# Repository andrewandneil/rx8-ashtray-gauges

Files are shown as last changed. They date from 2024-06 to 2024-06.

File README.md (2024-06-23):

# Mazda RX-8 Ashtray Gauges

As someone who likes knowing the vitals of my ever-so-fragile rotary engine, I wanted a way to monitor Oil Temperature, Oil Pressure, Coolant Temperature and Electrical System Voltage without needing big aftermarket gauges. I stumbled across Stephane Gilbert's work, where he built a small gauge system for coolant temperature, pressure and battery voltage, but it wasn't a perfect fit for me. I decided to take his basis, and modify it to my need. After several months of toiling around, I have finally produced this:

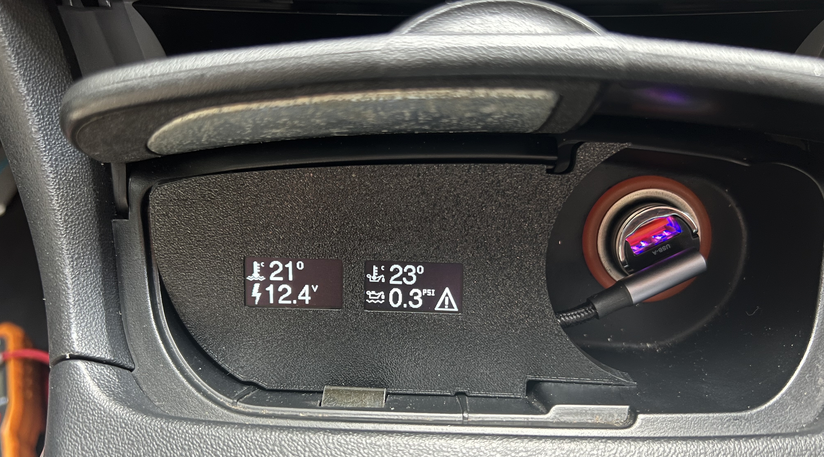
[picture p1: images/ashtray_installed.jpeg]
RX8 Ashtray Gauges Installed


This project doesn't use the OBDII port, instead relying on deidcated sensors. For both oil and coolant temperature AEM-30-2012 sensors were used and for oil pressure a 200 PSI pressure transducer was used. Electrical system voltage is calculated using the supplied power on board.

The design uses two PCBs, one PCB that houses the electronics, and another PCB inside the ashtray cavity to breakout the connectors for screens and sensors.

## Features
- Coolant Temperature Monitoring & Warning.
- Oil Temperature and Pressure Monitoring & Warning.
- System Voltage Monitoring & Warning.
- Screen auto-off when ashtray lid is closed.
- Optional LED warning lights when temperature, pressure or voltage is out of user specified limits.
- Optional buzzer sound when temperature, pressure or voltage is out of user specified limits. [NOT IMPLEMENTED ATM]

## Sensors
If you're building this yourself, this is where you can go your own route, you may prefer to use the oil filter sandwich plate, in which case disregard anything below. You also shouldnt need a 200 PSI sensor if you're using the sandwich plate, a 100 PSI sensor would be more appropriate (do your own research, this is what I've found searching around). You may also prefer to add your coolant temp sensor to the main radiator hose, in which case of course there are guides out there for that.

#### My Oil Temperature Sensor Location:
A modified banjo bolt with a 1/8NPT thread cut into the top is used. Add thread sealant to the NPT threads and not to the banjo bolt threads (that's what the crush washers are for). Mounted to the banjo bolt on the front passanger side oil cooler.

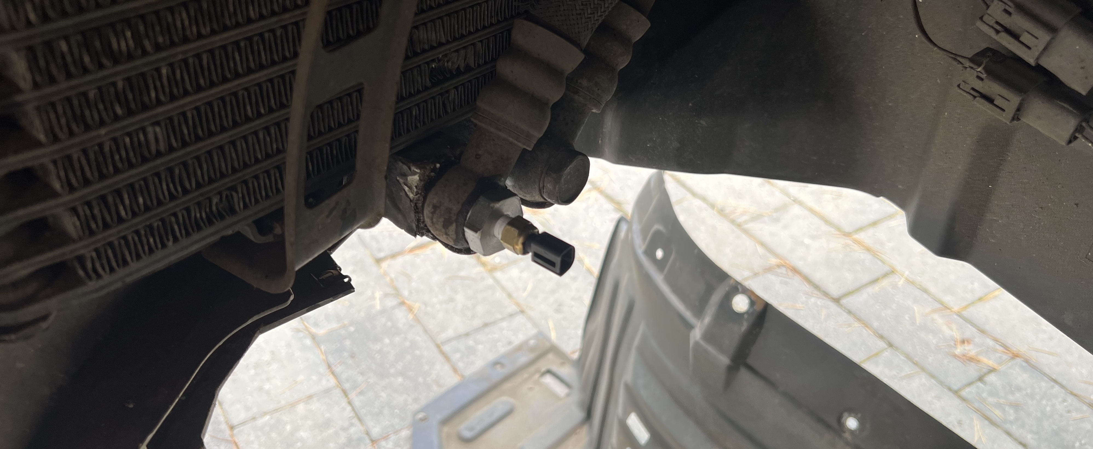
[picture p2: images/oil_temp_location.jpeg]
Oil Temp Sensor Location


#### My Oil Pressure Sensor Location:
A modified banjo bolt with a 1/8NPT thread cut into the top is used. Add thread sealant to the NPT threads and not to the banjo bolt threads (that's what the crush washers are for). Mounted to the banjo bolt on the feed line to the oil cooler.

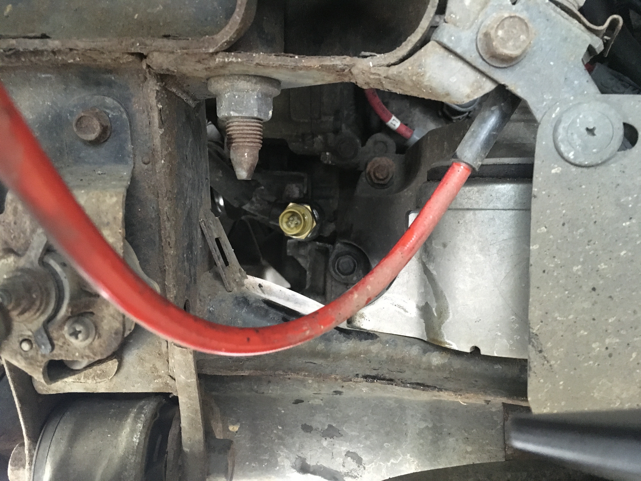
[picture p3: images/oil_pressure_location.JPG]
Oil Pressure Sensor Location


#### My Coolant Temperature Sensor Location:
A Racing Beat RX-8 Water Temp Sensor Hose Adapter is used with a 3/8 to 1/8 step down adapter to fit the 1/8NPT thread of the sensor. Add thread sealant to the threads on both the adapter and sensor. Fitted to the heater core hose located on the passanger side.

Coolant Temp Sensor Location

## 3D Printing
The cases for the electronics and the OLED screen holders are designed to be 3D printed by a standard FDM printer. 

### Electronics Housing
Recommended print settings:
- PETG or ABS/ASA (don't use PLA as it will warp when exposed to the sun or heat)
- 0.2mm Layer Height

You'll also need:
- x6 M3 Heat set inserts (OD: 4mm, Length: 4.2mm)
- x6 M3x10 Bolts
- x2 M3 Washers (for clamping the CPT power item to the board)

### OLED Screen Holder
Recommended print settings:
- PETG or ABS/ASA (don't use PLA as it will warp when exposed to the sun or heat)
- 0.1mm or 0.15mm Layer Height

You'll also need:
- x5 M3 Heat set inserts (OD: 4mm, Length: 4.2mm)
- x2 M3x10 Bolts
- x3 M3x4 Bolts

### OLED Screen Spacers
Print two, one for each oled screen.

Recommended print settings:
- PETG or ABS/ASA (don't use PLA as it will warp when exposed to the sun or heat)
- 0.2mm Layer Height

You'll also need:
- x8 M2.5x8 Dome Head Bolts (must be low profile)
- x8 M2.5 Nuts
- x8 M2.5 Washers

## Useful Links
A guide for adding the oil temperature and pressure sensors: https://www.rx8club.com/series-i-do-yourself-forum-73/diy-oil-temp-pressure-sender-install-modified-banjo-bolts-235867/

rx8-coolant-monitor by Stephane Gilbert (topolittle): https://github.com/topolittle/rx8-coolant-monitor

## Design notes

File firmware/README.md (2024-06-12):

# The Firmware

Open this folder using PlatformIO in Visual Studio Code (or VSCodium). Ensure you have the Adafruit GFX Library and Adafruit SSD1306 libraries installed (these should install automatically from the platformio.ini file on first opening).

IMPORTANT: To ensure proper temperature, pressure and battery voltage calculations, you need to measure the exact resistance of `R3`, `R4`, `R8`, `R9`, `R10` and `R11` and add these values to the marked sections in the `coolant_monitor.h` file.

For example, if you measured a resistance of 13.9K on the coolant high side resistor, change the line:
- `#define COOL_THERMISTOR_RESISTOR_REFERENCE_HIGH 15020.0` to `#define COOL_THERMISTOR_RESISTOR_REFERENCE_HIGH 13900.0`

You must add the `.0` at the end as the value must be reported as a float.

Build this by pressing the checkmark in the bottom left of the VS Code window, and then upload it to the Teensy using the onboard micro-USB port by pressing the right hand arrow in VS Code.

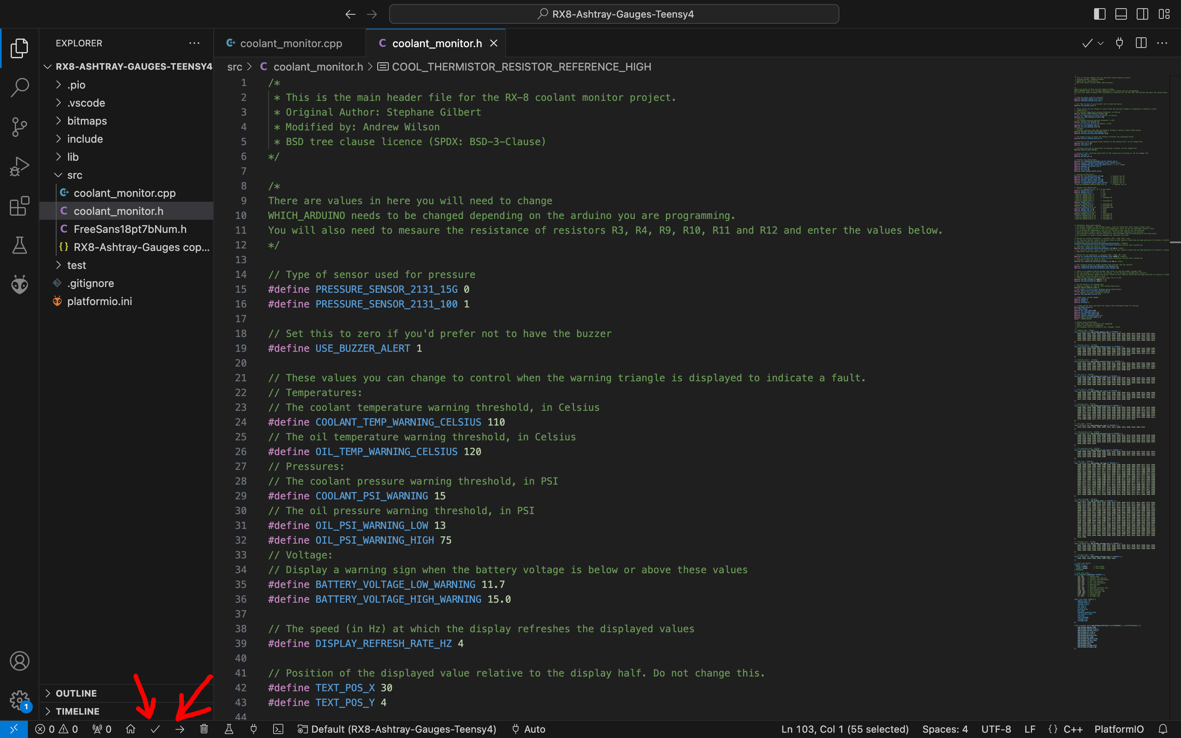
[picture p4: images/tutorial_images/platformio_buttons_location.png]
PlatformIO Button Locations


(Better tutorial to follow :) )

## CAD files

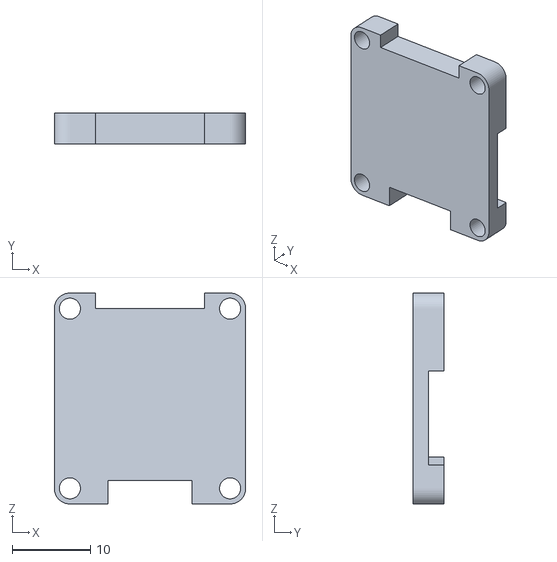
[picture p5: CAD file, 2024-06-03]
3d-models/ashtray_screens/ashtray_screen_spacer.stl
24.5 x 3.94 x 27.0

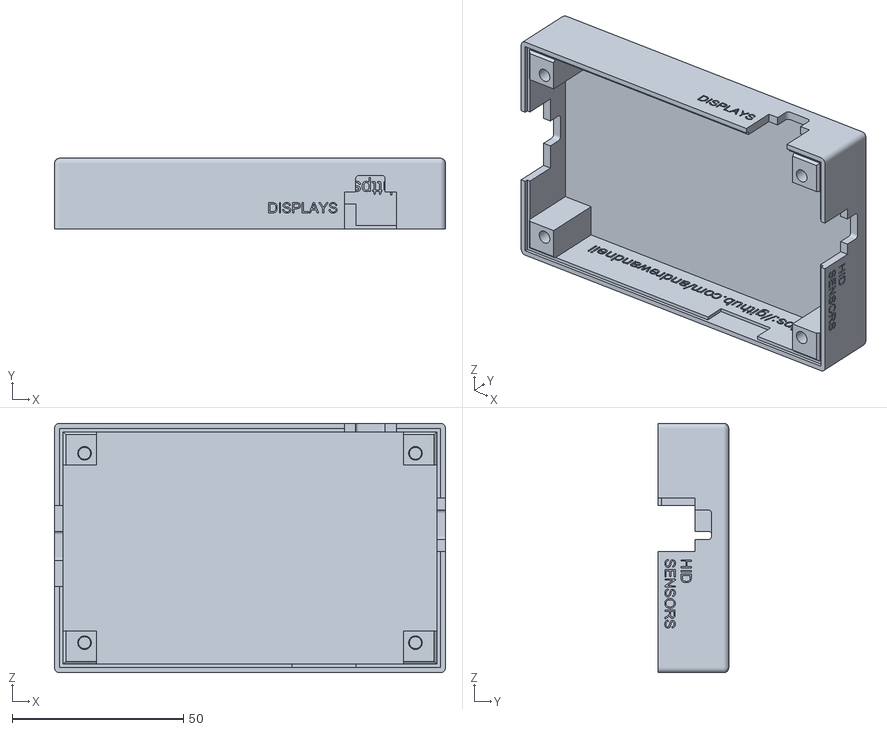
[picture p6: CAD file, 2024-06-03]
3d-models/pcb_housing/pcb_enclosure_top.stl
114.0 x 20.6 x 72.8

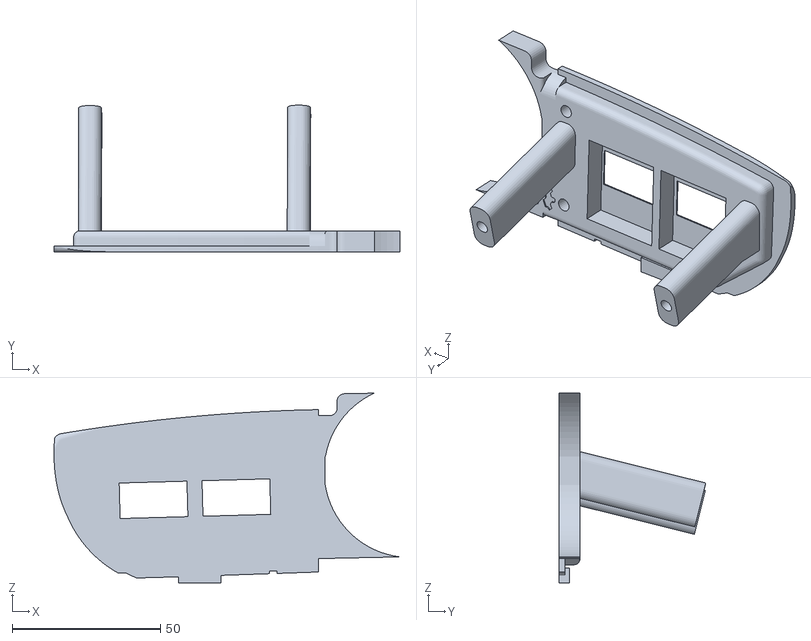
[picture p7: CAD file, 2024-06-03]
3d-models/ashtray_screens/ashtray_screen_no_led.stl
116.9 x 49.5 x 64.1

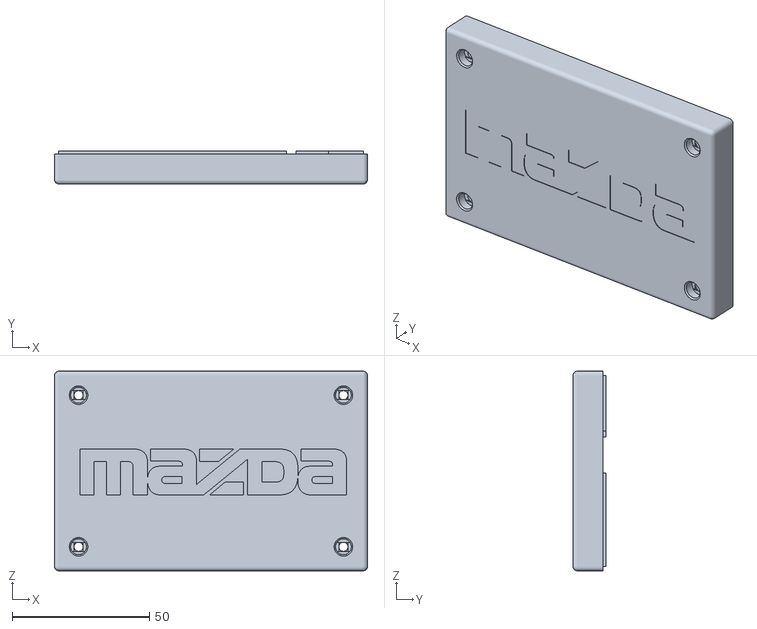
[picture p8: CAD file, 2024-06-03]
3d-models/pcb_housing/pcb_enclosure_bottom.stl
114.0 x 12.0 x 72.8

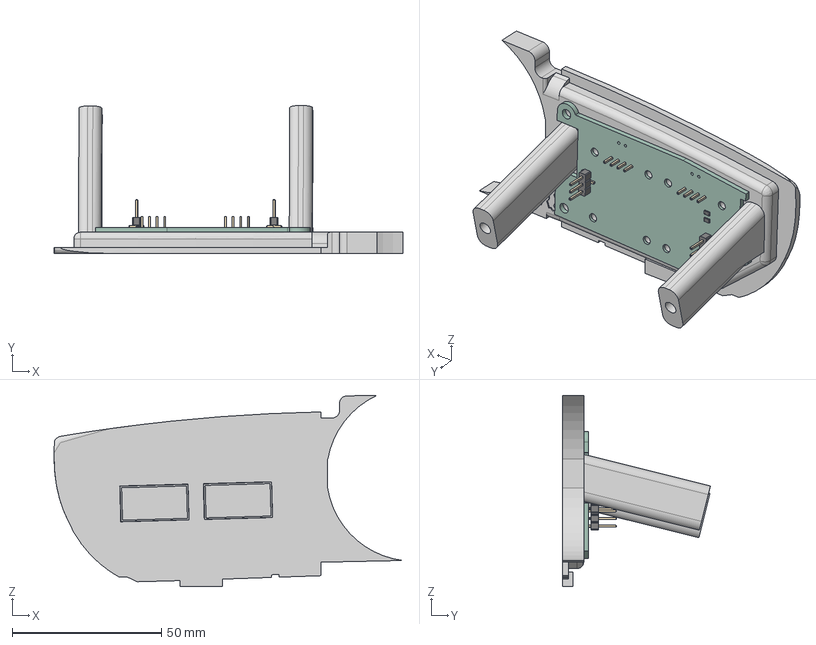
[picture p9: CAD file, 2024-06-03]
3d-models/ashtray_screens/ashtray_gauges_assembely.step
116.9 x 49.5 x 64.1 mm
PinHeader_1x04_P254mm_Vertical (3) x 2
PinHeader_1x03_P254mm_Vertical_SMD_Pin1Left (1)
PinHeader_1x03_P254mm_Vertical_SMD_Pin1Left (3)
R_0805_2012Metric (3)
R_0805_2012Metric (4)
_autosave-RX8 AG OLED and LED Mount_PCB
LED_0805_2012Metric (12)

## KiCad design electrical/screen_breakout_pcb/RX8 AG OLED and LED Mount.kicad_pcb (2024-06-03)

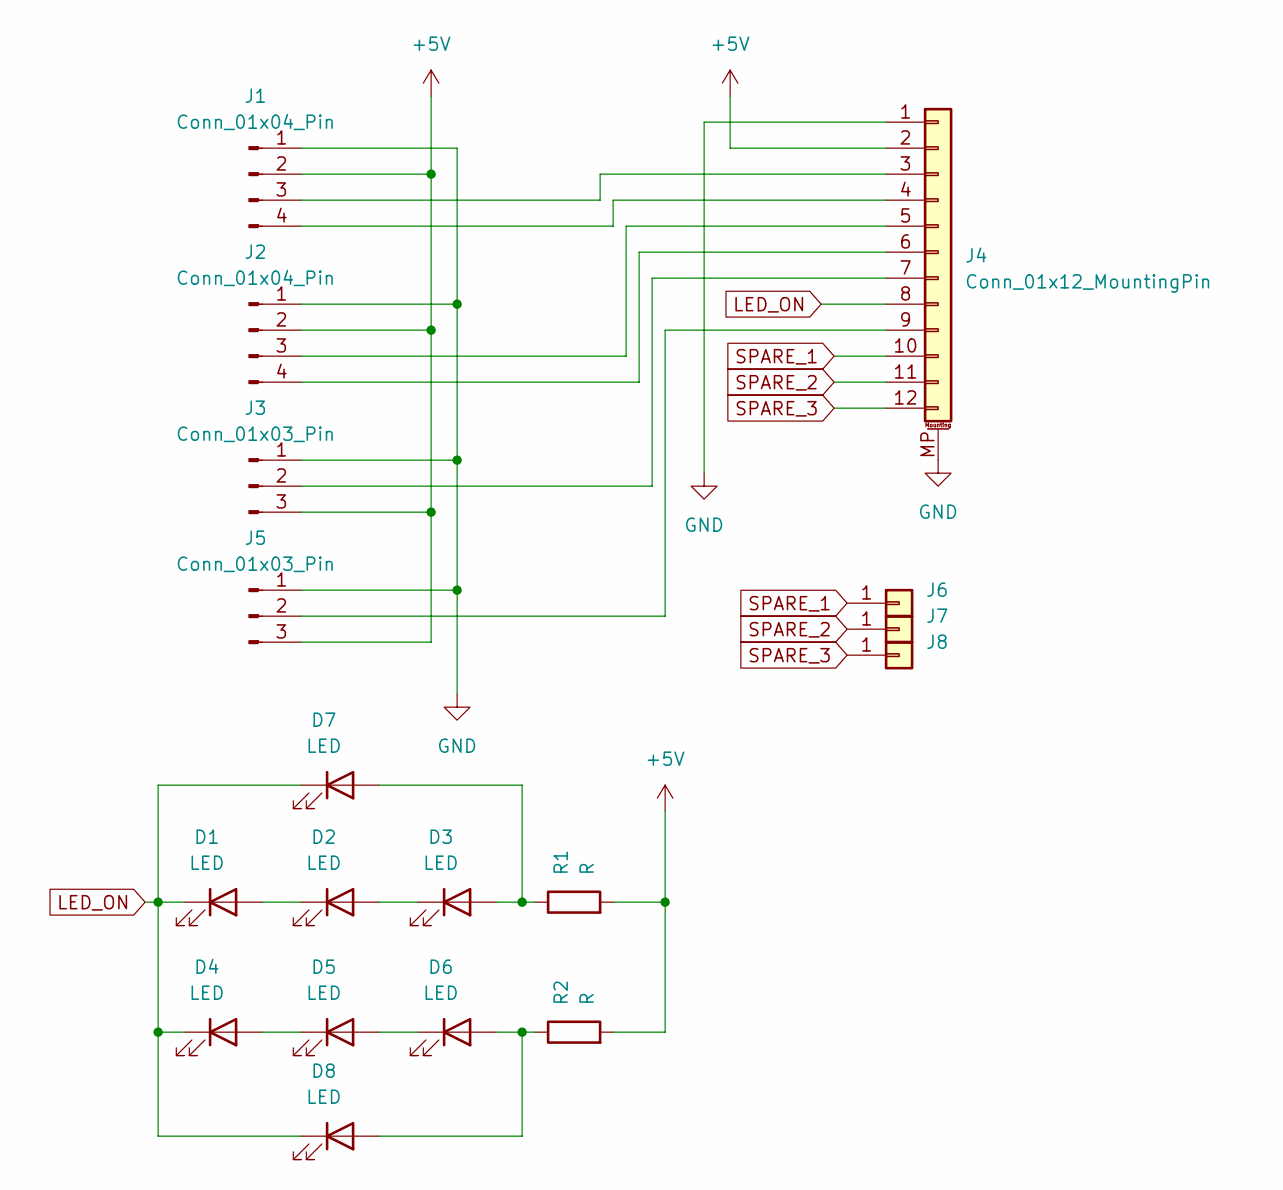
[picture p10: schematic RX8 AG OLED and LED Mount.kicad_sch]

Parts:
D1, D2, D3, D4, D5, D6: LED; LED_0805_2012Metric
D7, D8: LED; LED_D5.0mm
J1, J2: Conn_01x04_Pin; PinHeader_1x04_P2.54mm_Vertical
J3, J5: Conn_01x03_Pin; PinHeader_1x03_P2.54mm_Vertical_SMD_Pin1Left
J4: Conn_01x12_MountingPin; JST_PH_B12B-PH-SM4-TB_1x12-1MP_P2.00mm_Vertical
J6, J7, J8: Conn_01x01; SolderWirePad_1x01_SMD_1x2mm
R1, R2: R; R_0805_2012Metric_Pad1.20x1.40mm_HandSolder

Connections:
+5V: J1.2, J2.2, J3.3, J4.2, J5.3, R1.2, R2.2
GND: J1.1, J2.1, J3.1, J4.1, J4.MP (MountPin), J5.1
LED_ON: D1.1 (K), D4.1 (K), D7.1 (K), D8.1 (K), J4.8
unnamed: D1.2 (A), D2.1 (K)
unnamed: D2.2 (A), D3.1 (K)
unnamed: D3.2 (A), D7.2 (A), R1.1
unnamed: D4.2 (A), D5.1 (K)
unnamed: D5.2 (A), D6.1 (K)
unnamed: D6.2 (A), D8.2 (A), R2.1
unnamed: J1.3, J4.3
unnamed: J1.4, J4.4
unnamed: J2.3, J4.5
unnamed: J2.4, J4.6
unnamed: J3.2, J4.7
unnamed: J4.9, J5.2
SPARE_1: J4.10, J6.1
SPARE_2: J4.11, J7.1
SPARE_3: J4.12, J8.1

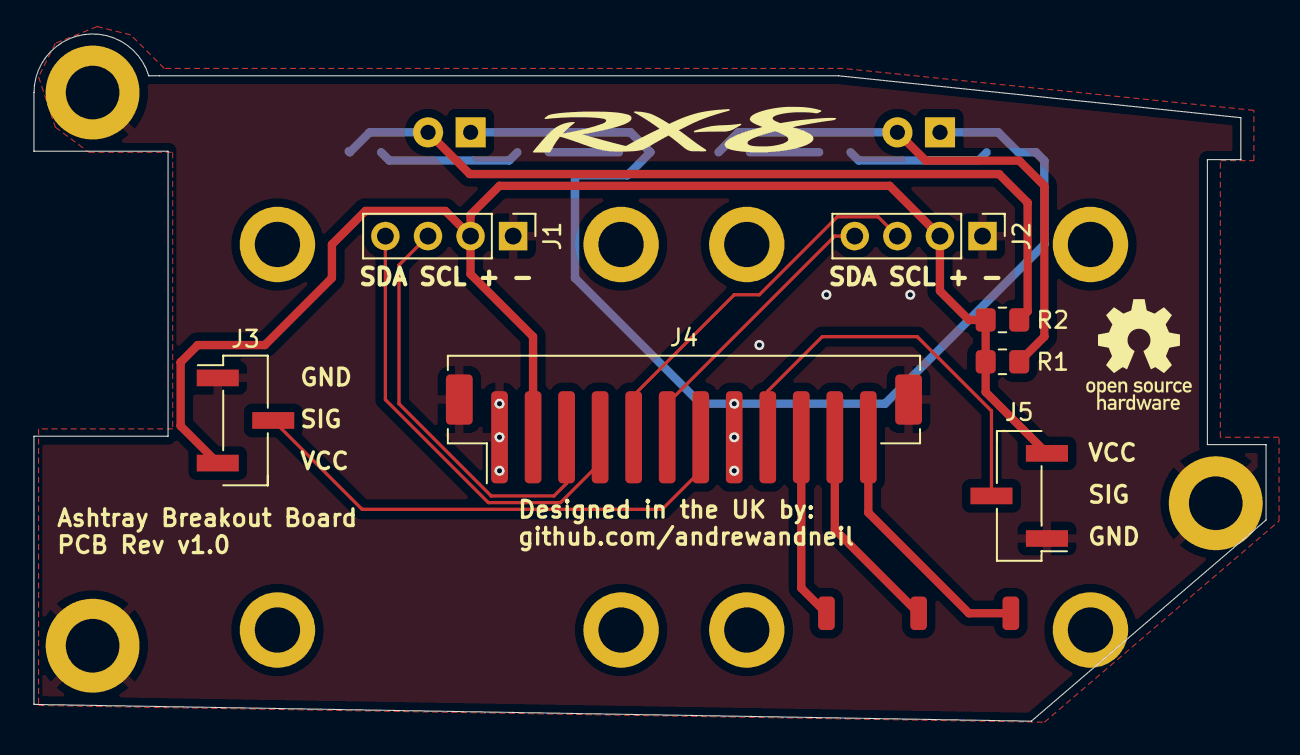
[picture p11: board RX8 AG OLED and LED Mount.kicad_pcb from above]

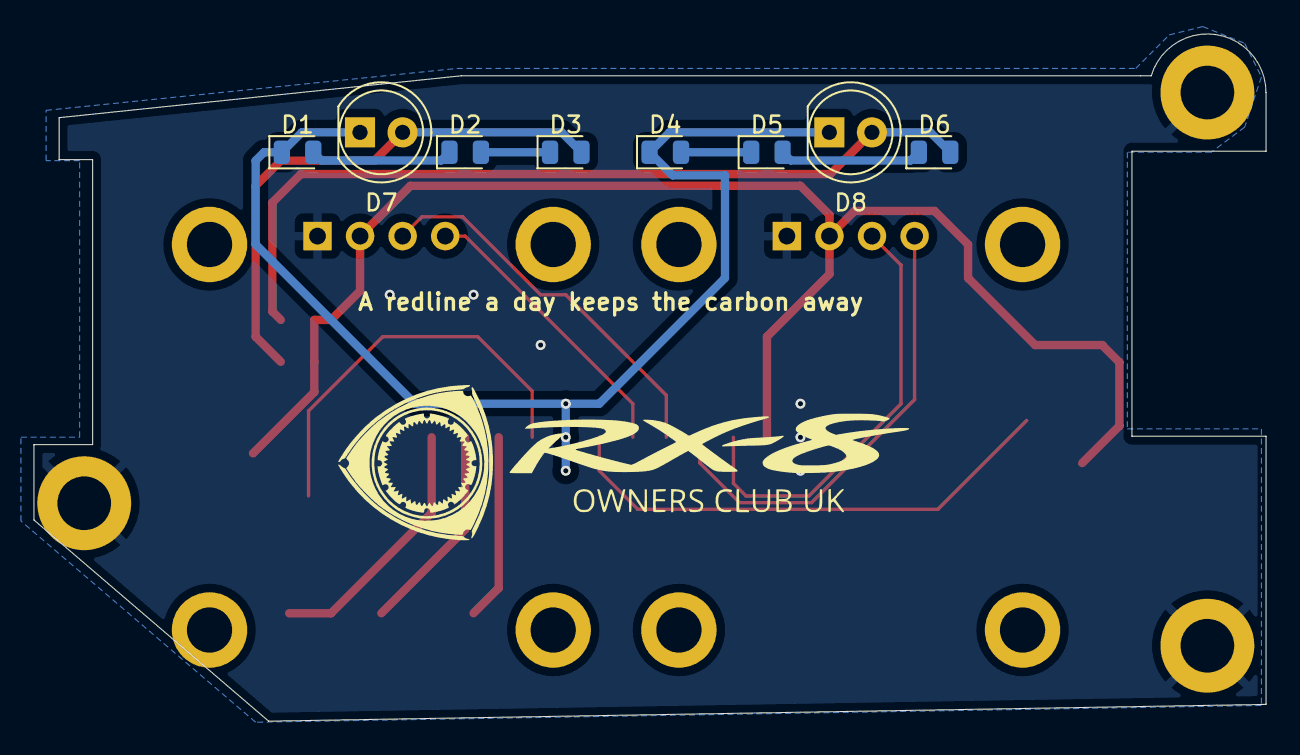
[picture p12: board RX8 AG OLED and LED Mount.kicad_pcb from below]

Board: 2 copper layers, 73.5 x 41.0 mm, 18 parts (8 on the bottom side), 18 nets.

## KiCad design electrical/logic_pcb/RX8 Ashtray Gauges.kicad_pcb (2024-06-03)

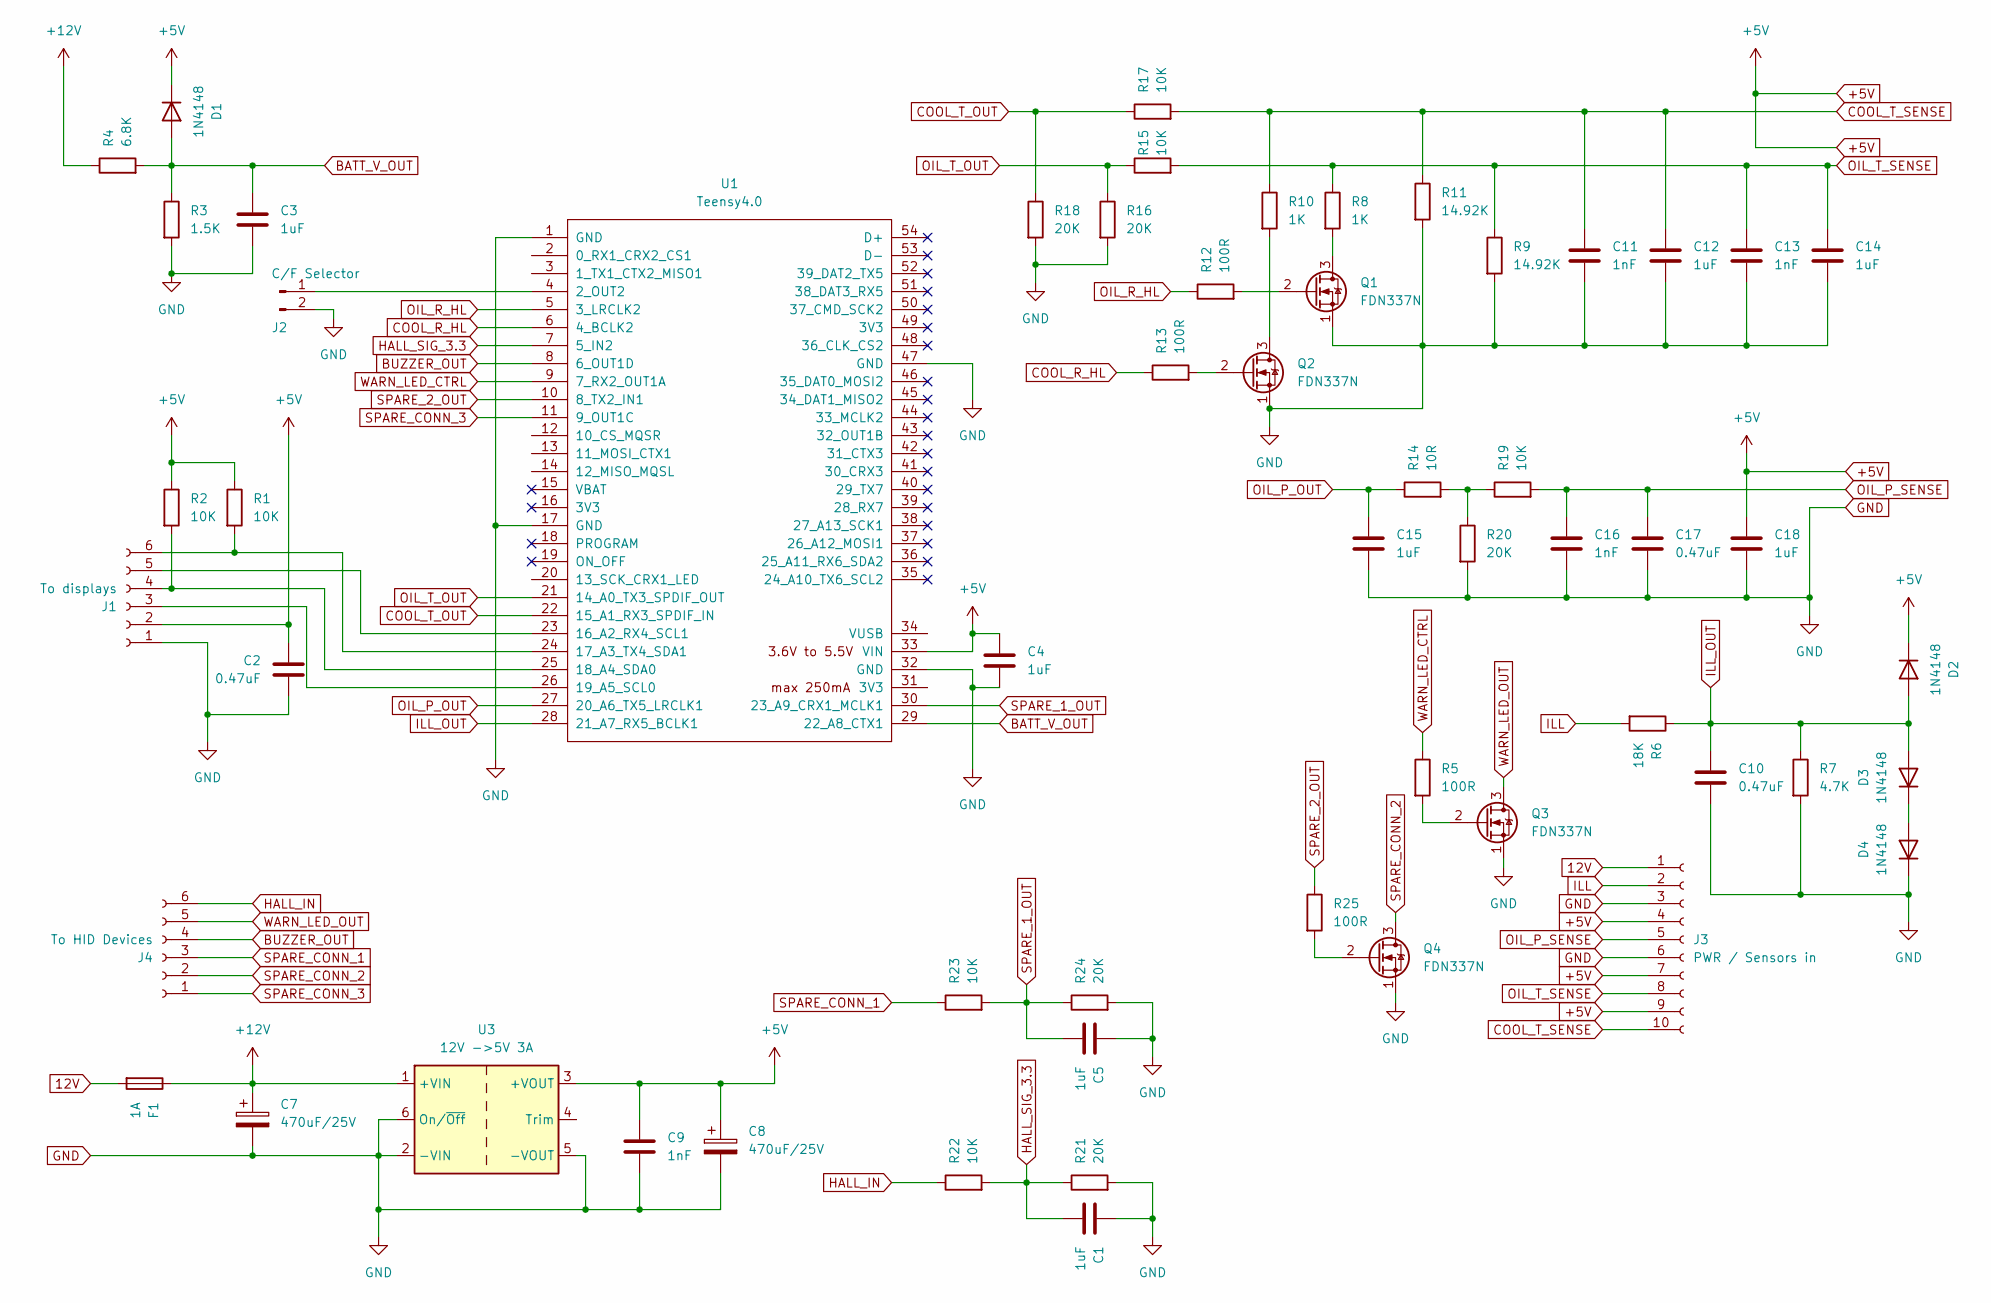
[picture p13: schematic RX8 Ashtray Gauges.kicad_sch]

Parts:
C1, C3, C4, C5, C12, C14, C15, C18: 1uF; C_Disc_D5.0mm_W2.5mm_P5.00mm
C2, C10, C17: 0.47uF; C_Disc_D5.0mm_W2.5mm_P5.00mm
C7, C8: 470uF/25V; CP_Radial_D8.0mm_P3.80mm
C9, C11, C13, C16: 1nF; C_Disc_D5.0mm_W2.5mm_P5.00mm
D1, D2, D3, D4: 1N4148; D_A-405_P7.62mm_Horizontal
F1: 1A; R_Axial_DIN0207_L6.3mm_D2.5mm_P10.16mm_Horizontal
J1: To displays; Molex_Mini-Fit_Jr_5569-06A2_2x03_P4.20mm_Horizontal
J2: C/F Selector; PinHeader_1x02_P2.54mm_Vertical
J3: PWR / Sensors in; Molex_Mini-Fit_Jr_5569-10A2_2x05_P4.20mm_Horizontal
J4: To HID Devices; Molex_Mini-Fit_Jr_5569-06A2_2x03_P4.20mm_Horizontal
Q1, Q2, Q3, Q4: FDN337N; SuperSOT-3
R1, R2, R15, R17, R19, R22, R23: 10K; R_Axial_DIN0207_L6.3mm_D2.5mm_P10.16mm_Horizontal
R3: 1.5K; R_Axial_DIN0207_L6.3mm_D2.5mm_P10.16mm_Horizontal
R4: 6.8K; R_Axial_DIN0207_L6.3mm_D2.5mm_P10.16mm_Horizontal
R5, R12, R13, R25: 100R; R_Axial_DIN0207_L6.3mm_D2.5mm_P10.16mm_Horizontal
R6: 18K; R_Axial_DIN0207_L6.3mm_D2.5mm_P10.16mm_Horizontal
R7: 4.7K; R_Axial_DIN0207_L6.3mm_D2.5mm_P10.16mm_Horizontal
R8, R10: 1K; R_Axial_DIN0207_L6.3mm_D2.5mm_P10.16mm_Horizontal
R9, R11: 14.92K; R_Axial_DIN0207_L6.3mm_D2.5mm_P10.16mm_Horizontal
R14: 10R; R_Axial_DIN0207_L6.3mm_D2.5mm_P10.16mm_Horizontal
R16, R18, R20, R21, R24: 20K; R_Axial_DIN0207_L6.3mm_D2.5mm_P10.16mm_Horizontal
U1: Teensy4.0; Teensy40_Simplified
U3: 12V ->5V 3A; CPT 7-12V to 5V DCDC Converter

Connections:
12V: F1.2, J3.1
+5V: C2.1, C4.1, C8.1, C9.1, C18.1, D1.1 (K), D2.1 (K), J1.2, J3.4, J3.7, J3.9, R1.1, R2.1, U1.33 (VIN), U3.3 (+VOUT)
+12V: C7.1, F1.1, R4.1, U3.1 (+VIN)
BATT_V_OUT: C3.1, D1.2 (A), R3.1, R4.2, U1.29 (22_A8_CTX1)
BUZZER_OUT: J4.4, U1.8 (6_OUT1D)
COOL_R_HL: R13.1, U1.6 (4_BCLK2)
COOL_T_OUT: R17.1, R18.1, U1.22 (15_A1_RX3_SPDIF_IN)
COOL_T_SENSE: C11.1, C12.1, J3.10, R10.1, R11.1, R17.2
GND: C1.1, C2.2, C3.2, C4.2, C5.1, C7.2, C8.2, C9.2, C10.2, C11.2, C12.2, C13.2, C14.2, C15.2, C16.2, C17.2, C18.2, D4.1 (K), J1.1, J2.2, J3.3, J3.6, Q1.1 (S), Q2.1 (S), Q3.1 (S), Q4.1 (S), R3.2, R7.2, R9.2, R11.2, R16.2, R18.2, R20.2, R21.2, R24.2, U1.1 (GND), U1.17 (GND), U1.32 (GND), U1.47 (GND), U3.2 (-VIN), U3.5 (-VOUT), U3.6 (On/~Off); also elsewhere on the board
HALL_IN: J4.6, R22.1
HALL_SIG_3.3: C1.2, R21.1, R22.2, U1.7 (5_IN2)
ILL: J3.2, R6.2
ILL_OUT: C10.1, D2.2 (A), D3.2 (A), R6.1, R7.1, U1.28 (21_A7_RX5_BCLK1)
unnamed: D3.1 (K), D4.2 (A)
unnamed: J1.3, U1.26 (19_A5_SCL0)
unnamed: J1.4, R2.2, U1.25 (18_A4_SDA0)
unnamed: J1.5, U1.23 (16_A2_RX4_SCL1)
unnamed: J1.6, R1.2, U1.24 (17_A3_TX4_SDA1)
unnamed: J2.1, U1.4 (2_OUT2)
unnamed: Q1.3 (D), R8.2
unnamed: Q1.2 (G), R12.2
unnamed: Q2.3 (D), R10.2
unnamed: Q2.2 (G), R13.2
unnamed: Q3.2 (G), R5.2
unnamed: Q4.2 (G), R25.2
unnamed: R14.2, R19.1, R20.1
OIL_P_OUT: C15.1, R14.1, U1.27 (20_A6_TX5_LRCLK1)
OIL_P_SENSE: C16.1, C17.1, J3.5, R19.2
OIL_R_HL: R12.1, U1.5 (3_LRCLK2)
OIL_T_OUT: R15.1, R16.1, U1.21 (14_A0_TX3_SPDIF_OUT)
OIL_T_SENSE: C13.1, C14.1, J3.8, R8.1, R9.1, R15.2
SPARE_1_OUT: C5.2, R23.2, R24.1, U1.30 (23_A9_CRX1_MCLK1)
SPARE_2_OUT: R25.1, U1.10 (8_TX2_IN1)
SPARE_CONN_1: J4.3, R23.1
SPARE_CONN_2: J4.2, Q4.3 (D)
SPARE_CONN_3: J4.1, U1.11 (9_OUT1C)
WARN_LED_CTRL: R5.1, U1.9 (7_RX2_OUT1A)
WARN_LED_OUT: J4.5, Q3.3 (D)

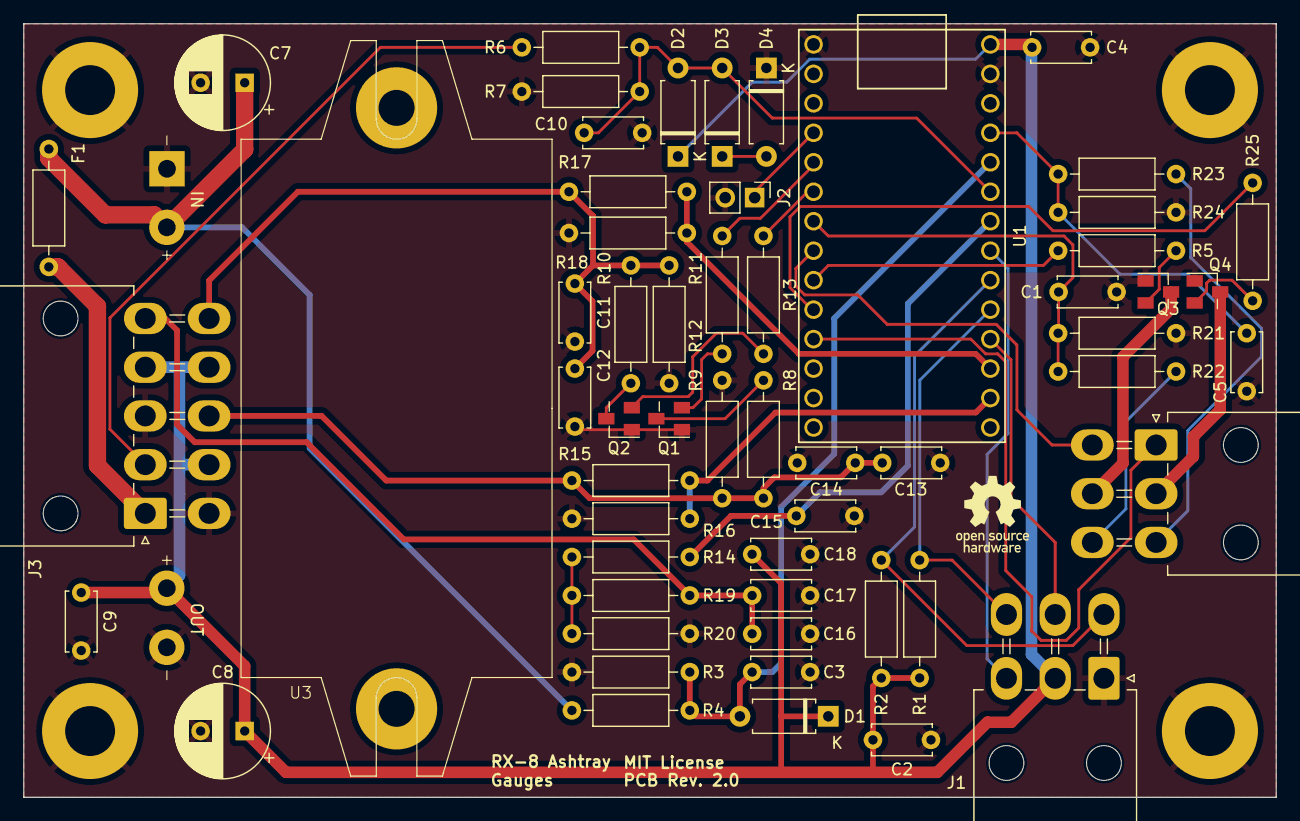
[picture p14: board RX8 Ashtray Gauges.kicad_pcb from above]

Board: 2 copper layers, 108.0 x 66.7 mm, 61 parts (0 on the bottom side), 38 nets.

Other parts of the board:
J5, J6, J7, J8: Conn_01x01; Pin_D1.0mm_L10.0mm

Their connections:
GND: J5.1, J6.1, J7.1, J8.1; also elsewhere on the board

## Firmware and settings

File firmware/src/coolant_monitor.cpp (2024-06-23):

/* 
 * This is the main source code for the RX-8 Ashtray Gauges project.
 * It targets a Teensy 4.0
 * Original Author: Stephane Gilbert
 * Modified by: Andrew Wilson
 * BSD tree clause licence (SPDX: BSD-3-Clause)
*/

#include <Wire.h>
#include <Adafruit_GFX.h>
#include <Adafruit_SSD1306.h>
#include "coolant_monitor.h"
#include "FreeSans18pt7bNum.h"

#define OLED_RESET 4 // Reset for Adafruit SSD1306

// Using this constructor to have the maximum I2C communication speed.
Adafruit_SSD1306 display_1(128, 64, &Wire, OLED_RESET);
Adafruit_SSD1306 display_2(128, 64, &Wire1, OLED_RESET);

// This timer is used to run the buzzer for a user defined number of seconds.
// Called on entering fault or warning state.
IntervalTimer buzzerTimer;

// Values to cache the current reading in memory
float current_oil_temp;
float current_oil_psi;
bool oil_thermistor_reference_mode_high = true;
float current_coolant_temp;
//float current_coolant_psi;
float current_supply_voltage;
bool cool_thermistor_reference_mode_high = true;

// General booleans we can check to see what's going on
bool temperatureUnitIsFahrenheit = false;
bool pressureUnitIsBar = false;
bool currentDaylight = true;
bool lidClosed = false;

bool in_alert = false; 
bool buzzer_currently_playing = false;

bool coolant_temp_warn_happened = false;
//bool coolant_psi_warn_happened = false;
bool oil_temp_warn_happened = false;
bool oil_psi_warn_happened = false;
bool voltage_warn_happened = false;

// Read the specified analogue input pin many times and return the mean
// pin: The pin on which the analogue read will occur
// Return: A float between 0 and 1023 representing the analogue value on the specified pin
float readAnalogInputRaw(uint8_t pin)
{
    uint16_t cumulative_value = 0;
    int single_value;

    // The first read is a dummy read only to warm up the ADC, so we Loop from zero to
    // ANALOG_SAMPLES_COUNT inclusively, in fact ANALOG_SAMPLES_COUNT + 1 times.
    for (size_t i = 0; i <= ANALOG_SAMPLES_COUNT; i++)
    {
        single_value = analogRead(pin);

        // If it's the first read, force the value to zero, it it will not be taken into account
        cumulative_value += i > 0 ? single_value : 0;
        delay(ANALOG_DELAY_BETWEEN_ACQUISITIONS);
    }

    // Return the arithmetic mean
    return (float)cumulative_value / (float)ANALOG_SAMPLES_COUNT;
}

// Returns the voltage on the specified pin
// pin: The pin on which the analogue read will occur
// Return: A float representing the voltage read at the specified pin
float readVoltage(uint8_t pin)
{
    float value = readAnalogInputRaw(pin);

    return (MAX_ANALOGUE_VOLTAGE / 1023) * value;
}

// Invalidate the display value so the next reading will force the display to be redrawn
void forceDisplayRefresh()
{
    current_oil_psi = __FLT_MIN__;
    current_oil_temp = __FLT_MIN__;
    current_coolant_temp = __FLT_MIN__;
    current_supply_voltage = __FLT_MIN__;
}

// Draw an icon using specified display object
// display: An instance reference of the Adafruit_SSD1306 class
// icon: The specific icon to draw, emum value
// xpos, ypos: The top left corner to start the drawing 
void drawIcon(Adafruit_SSD1306 &display, const Icon icon, const uint8_t xpos, const uint8_t ypos)
{
    display.drawBitmap(
        (uint16_t)xpos,
        (uint16_t)ypos,
        epd_bitmap_allArray[(uint8_t)icon],
        pgm_read_byte(&iconSize[(uint8_t)icon].width),
        pgm_read_byte(&iconSize[(uint8_t)icon].height),
        1);
}

// Draw the warning icon using the the specified display object
// We also turn on the warning LED to notify the user of warning state
// display: An instance reference of the Adafruit_SSD1306 class, the display to write to
// half: True to print on the top half of display, False to print on the bottom half of display
void drawWarning(Adafruit_SSD1306 &display, bool half)
{
    if (half) {
        drawIcon(display, Icon::warning_icon, 95, 0);
    } else {
        drawIcon(display, Icon::warning_icon, 95, 0 + DISPLAY_HALF_TWO);
    }
    #if ENABLE_WARNING_LEDS
    digitalWrite(WARNING_LED_OUTPUT_PIN, HIGH);
    in_alert = true;
    #endif
}

// Display a fault message using the the specified display object
// We also turn on the warning LED to notify the user of fault state
// display: An instance reference of the Adafruit_SSD1306 class, the display to write to
// half: True to print on the top half of display, False to print on the bottom half of display
void displayFault(Adafruit_SSD1306 &display, bool half)
{
    if (half) {
        drawIcon(display, Icon::fault_message, 11, 3);
    } else {
        drawIcon(display, Icon::fault_message, 11, 3 + DISPLAY_HALF_TWO);
    }

    #if ENABLE_WARNING_LEDS
    digitalWrite(WARNING_LED_OUTPUT_PIN, HIGH);
    in_alert = true;
    #endif

    // Ensure if we go out of fault, the display will refresh the actual value
    forceDisplayRefresh();
}

// Sets the reference resistor (pull down) for the oil thermistor
// value: True to set the high resistor value, False to select the low resistor value.
void setThermistorHighReferenceOil(const bool value)
{
    // The logic is inverted here by the FDN337N on the PCB
    digitalWrite(OIL_THERMISTOR_REFERENCE_SELECT_OUTPUT_PIN, value ? LOW : HIGH);
    oil_thermistor_reference_mode_high = value;
}

// Sets the reference resistor (pull down) for the coolant thermistor
// value: True to set the high resistor value, False to select the low resistor value.
void setThermistorHighReferenceCoolant(const bool value)
{
    // The logic is inverted here by the FDN337N on the PCB
    digitalWrite(COOLANT_THERMISTOR_REFERENCE_SELECT_OUTPUT_PIN, value ? LOW : HIGH);
    cool_thermistor_reference_mode_high = value;
}

// Convert the provided temperature from Celsius to Fahrenheit
// temperature: The temperature to convert from Celsius
// Return: A float representing the converted temperature, in Fahrenheit
float convertToFahrenheit(float temperature)
{
    return temperature * 9.0 / 5.0 + 32.0;
}

// Convert the provided pressue from PSI to Bar.
// pressure: The pressure to convert from PSI
// Return: A float representing the converted pressure, in Bar.
float convertToBar(float pressure) 
{
    return (pressure / 14.5038);
}

// Read the coolant/oil thermistor resistor value and convert it to temperature in Celsius
// using the Steinhart-Hart equation.
// TC: The variable that will hold the returned temperature value
// pinRead: The pin we are reading our analogue voltage from
// Return: ENOERR if the conversion succeeded and the value has been placed in the TC parameter, otherwise the error code
// Note: The function also manages the pull-down resistor set related to the sensor
int getFluidTempCelsius(float &TC, uint8_t pinRead)
{
    float tResValue;
    float logTResValue;
    float TK;
    float analogueValue;
    float t_res_ref;

    // The constant values for the AEM-30-2012 have been calculated with this online calculator:
    // https://www.thinksrs.com/downloads/programs/therm%20calc/ntccalibrator/ntccalculator.html
    // The reference resistor and temperature used for the calculator was extracted from the
    // following datasheet from AEM:
    // https://documents.aemelectronics.com/techlibrary_30-2012_water_temp_sensor_kit.pdf
    float c1 = 1.144169514e-3;   // -40C, 402392 OHMs4
    float c2 = 2.302830665e-4;   // 50C, 3911 OHMs
    float c3 = 0.8052469400e-7;  // 150C, 189.3 OHMs

    // Get the analogue value on the input pin
    analogueValue = readAnalogInputRaw(pinRead);

    // (2.878/5)*1023 = 588.8
    // LOW: 981 HIGH: 15090
    // 981 * (1023/588.8-1) = 721
    // log(721) = 2.8579
    // (1.0 / (0.001144169514 + (0.0002302830665 * 2.8579) + (0.00000008052469400 * 2.8579 * 2.8579 * 2.8579))) = 554.26

    // Avoid dividing by zero
    if (analogueValue == 0) {
        return EDIVZERO;
    }

    // Discard any values that do not make sense
    if (analogueValue < 0) {
        return ERANGE;
    }

    // Use the correct pull down resistor reference value according to the actual configured value
    if (pinRead == OIL_ANALOG_INPUT_PIN) {
        t_res_ref = oil_thermistor_reference_mode_high ? OIL_THERMISTOR_RESISTOR_REFERENCE_HIGH : OIL_THERMISTOR_RESISTOR_REFERENCE_LOW;
    } else {
        t_res_ref = cool_thermistor_reference_mode_high ? COOL_THERMISTOR_RESISTOR_REFERENCE_HIGH : COOL_THERMISTOR_RESISTOR_REFERENCE_LOW;
    }

    // Compute the thermistor resistor value, using the equation R2 = R1 * (Vin / Vout - 1)
    tResValue = (t_res_ref * (1023.0 / ((float)analogueValue) - 1.0));

    // Convert the thermistor resistor value to temperature in Kelvin using the Steinhart-Hart equation
    logTResValue = log(tResValue);
    TK = (1.0 / (c1 + c2 * logTResValue + c3 * logTResValue * logTResValue * logTResValue));

    // Ensure the temperature is between the sensor range: 233.15K to 425.15K (-40C to 150C)
    if (TK < 233.15 || TK > 423.15) {
        return ERANGE;
    }

    // Convert the temperature from Kelvin to Celsius
    TC = TK - 273.15;
    
    if (pinRead == OIL_ANALOG_INPUT_PIN) {
        // Manage the oil pull-down resistor reference for the next run
        if (oil_thermistor_reference_mode_high && TC > THERMISTOR_RESISTOR_REFERENCE_LOW_THRESHOLD)
            setThermistorHighReferenceOil(false);

        if (! oil_thermistor_reference_mode_high && TC < THERMISTOR_RESISTOR_REFERENCE_HIGH_THRESHOLD)
            setThermistorHighReferenceOil(true);
    } else {
        // Manage the coolant pull-down resistor reference for the next run
        if (cool_thermistor_reference_mode_high && TC > THERMISTOR_RESISTOR_REFERENCE_LOW_THRESHOLD)
            setThermistorHighReferenceCoolant(false);

        if (! cool_thermistor_reference_mode_high && TC < THERMISTOR_RESISTOR_REFERENCE_HIGH_THRESHOLD)
            setThermistorHighReferenceCoolant(true);
    }
    
    return ENOERR;
}

// Get the Coolant/Oil pressure in PSIG.
// PSIG is PSI above ambient pressure.
// psi: The variable that will hold the returned PSI value
// sensorType: The type of pressure sensor used for the fluid
// pinRead: The pin we are reading our analogue voltage from
// Return: ENOERR if the conversion succeeded and the value has been placed in the psi
//         parameter, otherwise the error code
int getFluidPsi(float &psi, int sensorType, uint8_t pinRead)
{
    float volts_32bit, volts;
    #if DEBUG_VALUES
    volts_32bit = 1.5;
    #else
    volts_32bit = readVoltage(pinRead);
    #endif

    // Because the Teensy 4.0's ADC has a max of 3.3V we need to convert the 0-3.3V range back to 0-5V
    volts = (volts_32bit / MAX_ANALOGUE_VOLTAGE) * 5;

    // Ensure the voltage is between the sensor range, otherwise return an error
    // Our range is 0.5 to 4.5, however, most sensors can run a little bit out of their rating
    // so we allow a slightly lower and higher min and max voltage here.
    if (volts < 0.4 || volts > 4.6) {
        return ERANGE;
    }

    switch (sensorType) {
        case 0:
            // AEM30-2131-100 or AEM30-2130-100
            // 100 PSI Sensor
            
            // Convert voltage to PSI
            // According to this datasheet, PSI = (25*(Voltage)) - 12.5
            // https://documents.aemelectronics.com/techlibrary_30-2131-100_sensor_data.pdf
            // https://documents.aemelectronics.com/techlibrary_30-2130-100_sensor_data.pdf
            psi = 25 * volts - 12.5;
            break;
        case 1:
            // AEM30-2131-150
            // 150 PSI Sensor

            // Convert voltage to PSI
            // According to this datasheet, PSI = (37.5*(Voltage)) - 18.75
            // https://documents.aemelectronics.com/techlibrary_30-2131-150_sensor_data.pdf
            psi = 37.5 * volts - 18.75;
            break;
        case 2:
            // 200 PSI Sensor

            // Convert voltage to PSI
            // Untested, but should be correct for linear voltage pressure sensors
            psi = 50 * volts - 25;
            break;
        case 3:
            // 300 PSI Sensor

            // Convert voltage to PSI
            // Untested, but should be correct for linear voltage pressure sensors
            psi = 75 * volts - 37.5;
            break;
        default:
            // sensorType is invalid so return an error
            return EINVALID;
    }

    if (psi < 0)
        psi = 0;

    return ENOERR;
}

// Read the supply voltage before the DC-DC converter
// It should be between 11.5 and 14.5
// voltage: The variable that will hold the returned voltage value
// Return: ENOERR if the conversion succeeded and the value has been placed in the voltage
//         parameter, otherwise the error code
int getSupplyVoltage(float &voltage)
{
    float volts, supply_voltage;
    #if DEBUG_VALUES
    volts = 2.3;
    #else
    volts = readVoltage(VOLTAGE_ANALOG_INPUT_PIN);
    #endif

    // Convert pin voltage to actual voltage based on the onboard tension divider
    supply_voltage = volts / (VOLTAGE_DIVIDER_R2 / (VOLTAGE_DIVIDER_R1 + VOLTAGE_DIVIDER_R2));

    // We can't be alive and have a supply voltage below 7V at the same time
    if (supply_voltage < 7)
        return ERANGE;
    
    voltage = supply_voltage;
    return ENOERR;
}

// Return true if the illumination (parking lights) are turned off, otherwise false
// Valid voltage are between 0V and 15V. Anything below 1.7v is considered day lignt
// Note: There a voltage divisor on the board that divides by roughly 4.830
// 18K and 4.7K = 22.7K / 4.7K = 4.830
// So 1.7V input would read .352V and 16V would read 3.31V at the analogue pin
// Note: There is no needs to use high precision function here. A simple analogue read
// is good enaugh.
bool isDayLight()
{
    float v;
    v = (float)analogRead(ILLUMINATION_ANALOG_INPUT_PIN) * (MAX_ANALOGUE_VOLTAGE / 1023.0);
    return (v < 0.35) ? true : false;
}

// If dayLight is true, set all displays to their maximum luminosity, dim them otherwise
void setDayLight(bool dayLight)
{
    currentDaylight = dayLight;
    display_1.ssd1306_command(SSD1306_SETCONTRAST);
    display_1.ssd1306_command(dayLight ? 0xFF : MINIMUM_BRIGHTNESS);
    display_2.ssd1306_command(SSD1306_SETCONTRAST);
    display_2.ssd1306_command(dayLight ? 0xFF : MINIMUM_BRIGHTNESS);
}

// Ensure the display intensity is set according to the current daylight status
void processDayLight()
{
    // Don't need to bother dimming the displays if the lid is closed.
    if (lidClosed)
        return;
    bool dayLight = isDayLight();
    if (dayLight != currentDaylight) {
        setDayLight(dayLight);
    }
}

// Return true if the hall effect sensor detects a magnet (ashtray lid is closed), otherwise false
// We're using the Teensy's internal pullup resistor, so no need for any fancy analogue checks.
// We can just read if the pin is high or low depending on the presence of the magnet.
bool isLidClosed() 
{
    return digitalRead(HALL_EFFECT_SENSOR_INPUT_PIN);
}

// If lidStatus is true, turn off all displays, otherwise turn them back on
void toggleDisplays(bool lidStatus) 
{
    lidClosed = lidStatus;
    if (lidStatus) {
        display_1.ssd1306_command(SSD1306_DISPLAYOFF);
        display_2.ssd1306_command(SSD1306_DISPLAYOFF);
    } else {
        forceDisplayRefresh();
        display_1.ssd1306_command(SSD1306_DISPLAYON);
        display_2.ssd1306_command(SSD1306_DISPLAYON);
    }
}

// Ensure the state of the displays is set according to the current lid status
void processLidStatus() 
{
    bool lidStatus = isLidClosed();
    if (lidStatus != lidClosed) {
        toggleDisplays(lidStatus);
    }
}

// Here a fault or warning state has been entered, so we activate and then deactivate the buzzer.
void handleBuzzer() 
{
    digitalWrite(ALERT_BUZZER_OUTPUT_PIN, buzzer_currently_playing);
    buzzer_currently_playing = false;
}
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
void loop()
{
    float oil_temp;
    float oil_psi;
    float coolant_temp;
    float supply_voltage;
    int err;
    int err2;

    // The following value are used to compute and enforce the refresh rate
    uint64_t startMs;
    int32_t elapsedMs;
    int32_t waitMs;

    // Sample the current timer counter
    startMs = millis();

    // Get oil pressure and temp and display
    // Also handle any faults that we've caught and display the appropriate message
    // in the appropriate place
    err = getFluidTempCelsius(oil_temp, OIL_ANALOG_INPUT_PIN);
    err2 = getFluidPsi(oil_psi, PRESSURE_SENSOR_200_PSI, OIL_PSI_ANALOG_INPUT_PIN);
    // We still want to process data when the lid is closed, but we don't want to display this on the screen.
    if (lidClosed) {
        if (err != ENOERR || err2 != ENOERR) {
            digitalWrite(WARNING_LED_OUTPUT_PIN, HIGH);
            in_alert = true;
        } else {
            if (oil_temp >= OIL_TEMP_WARNING_CELSIUS) {
                digitalWrite(WARNING_LED_OUTPUT_PIN, HIGH);
                in_alert = true;
            } else if (oil_psi >= OIL_PSI_WARNING_HIGH || oil_psi <= OIL_PSI_WARNING_LOW) {
                digitalWrite(WARNING_LED_OUTPUT_PIN, HIGH);
                in_alert = true;
            }
        }
    } else {
        if (err == ENOERR && err2 == ENOERR) {
            if (oil_psi != current_oil_psi || oil_temp != current_oil_temp) {
                display_1.clearDisplay();
                updateOilTemp(display_1, oil_temp);
                updateOilPsi(display_1, oil_psi);
                display_1.display();
            }
        } else if (err != ENOERR) {
            display_1.clearDisplay();
            displayFault(display_1, TOP_HALF);
            if (err2 != ENOERR) {
                displayFault(display_1, BOTTOM_HALF);
            } else {
                updateOilPsi(display_1, oil_psi);
            }
            display_1.display();
        } else {
            display_1.clearDisplay();
            updateOilTemp(display_1, oil_temp);
            displayFault(display_1, BOTTOM_HALF);
            display_1.display();
        }
    }
    

    // Get coolant temp and supply voltage and display
    // Also handle any faults that we've caught and display the appropriate message
    // in the appropriate place
    err = getFluidTempCelsius(coolant_temp, COOLANT_ANALOG_INPUT_PIN);
    err2 = getSupplyVoltage(supply_voltage);
    // We still want to process data when the lid is closed, but we don't want to display this on the screen.
    if (lidClosed) {
        // Save some processing if we are already in an alert state
        if (!in_alert) {
            if (err != ENOERR || err2 != ENOERR) {
                digitalWrite(WARNING_LED_OUTPUT_PIN, HIGH);
                in_alert = true;
            } else {
                if (coolant_temp >= COOLANT_TEMP_WARNING_CELSIUS) {
                    digitalWrite(WARNING_LED_OUTPUT_PIN, HIGH);
                    in_alert = true;
                } else if (supply_voltage >= BATTERY_VOLTAGE_HIGH_WARNING || supply_voltage <= BATTERY_VOLTAGE_LOW_WARNING) {
                    digitalWrite(WARNING_LED_OUTPUT_PIN, HIGH);
                    in_alert = true;
                }
            }
        }
    } else {
        if (err == ENOERR && err2 == ENOERR) {
            if (coolant_temp != current_coolant_temp) {
                display_2.clearDisplay();
                updateCoolantTemp(display_2, coolant_temp);
                updateSupplyVoltage(display_2, supply_voltage);
                display_2.display();
            }
        } else if (err != ENOERR) {
            display_2.clearDisplay();
            displayFault(display_2, TOP_HALF);
            if (err2 != ENOERR) {
                displayFault(display_2, BOTTOM_HALF);
            } else {
                updateSupplyVoltage(display_2, supply_voltage);
            }
            display_2.display();
        } else {
            display_2.clearDisplay();
            updateCoolantTemp(display_2, coolant_temp);
            displayFault(display_2, BOTTOM_HALF);
            display_2.display();
        }
    }
    
    // Now we check if the lid is closed, handling it appropriately.
    //processLidStatus();
    // Now we check if the car has switched on/off lights, and handle state changes appropriately.
    processDayLight();

    #if ENABLE_WARNING_LEDS
    // Fault not detected so we swtich the LEDs off
    if (!in_alert)
        digitalWrite(WARNING_LED_OUTPUT_PIN, LOW);
    #endif

    // Wait the correct amount of time to respect the desired refresh rate
    // Note: There is no needs to take the timer overflow into account here. The timer overflows every
    //       50 days, which is much longer than a car would run continuously
    elapsedMs = (int32_t)(millis() - startMs);
    waitMs = int32_t((int32_t)((1.0 / (float)DISPLAY_REFRESH_RATE_HZ) * 1000.0) - (int32_t)elapsedMs);
    if (waitMs > 0)
        delay(waitMs);
}

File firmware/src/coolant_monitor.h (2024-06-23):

/* 
 * This is the main header file for the RX-8 Ashtray Gauges project.
 * Original Author: Stephane Gilbert
 * Modified by: Andrew Wilson
 * BSD tree clause licence (SPDX: BSD-3-Clause)
*/

/* 
 * There are values in here you will need to change.
 * You will need to mesaure the resistance of resistors R3, R4, R8, R9, R10 and R11 and enter the values below.
*/

// Set this to zero if you'd prefer not to have the buzzer
// #define USE_BUZZER_ALERT 1

// Set this to zero if you don't want LEDs in a warning state
#define ENABLE_WARNING_LEDS 1

#define DEBUG_VALUES 0

// These values you can change to control when the warning triangle and warning LED is displayed to indicate a fault.
// Temperatures:
// The coolant temperature warning threshold, in Celsius
#define COOLANT_TEMP_WARNING_CELSIUS 110
// The oil temperature warning threshold, in Celsius
#define OIL_TEMP_WARNING_CELSIUS 120
// Pressures:
// The coolant pressure warning threshold, in PSI
#define COOLANT_PSI_WARNING 15
// The oil pressure warning threshold, in PSI
#define OIL_PSI_WARNING_LOW 13
#define OIL_PSI_WARNING_HIGH 150
// Voltage:
// Display a warning sign when the battery voltage is below or above these values
#define BATTERY_VOLTAGE_LOW_WARNING 11.5
#define BATTERY_VOLTAGE_HIGH_WARNING 15.0

// The speed (in Hz) at which the displays refresh the displayed values
#define DISPLAY_REFRESH_RATE_HZ 5 //4

// Position of the displayed value relative to the display half. Do not change this.
#define TEXT_POS_X 30
#define TEXT_POS_Y 4

// Distance from top to second half of display in pixels. Do not change this.
#define DISPLAY_HALF_TWO 32

// Values to tell functions which half of the screen we're printing on. Do not change this.
#define TOP_HALF 1
#define BOTTOM_HALF 0

/*
 * Teensy Pin Definitions
 * Correct as of PCB rev 2.2
 */
// Digital pins definitions
#define TEMPERATURE_UNIT_SELECTOR_INPUT_PIN 2 // C or F Jumper
#define OIL_THERMISTOR_REFERENCE_SELECT_OUTPUT_PIN 3
#define COOLANT_THERMISTOR_REFERENCE_SELECT_OUTPUT_PIN 4
#define HALL_EFFECT_SENSOR_INPUT_PIN 5
#define ALERT_BUZZER_OUTPUT_PIN 6
#define WARNING_LED_OUTPUT_PIN 7
#define SPARE_2_OUPUT_PIN 8
#define PRESSURE_UNIT_SELECTOR_INPUT_PIN 10
#define SCL1_PIN 16
#define SDA1_PIN 17
#define SDA0_PIN 18
#define SCL0_PIN 19

// Analogue pin definition
#define OIL_ANALOG_INPUT_PIN A0             // Digital out 14
#define COOLANT_ANALOG_INPUT_PIN A1         // Digital out 15
// A2, A3, A4, A5 are SCL & SDA pins
#define OIL_PSI_ANALOG_INPUT_PIN A6         // Digital out 20
#define ILLUMINATION_ANALOG_INPUT_PIN A7    // Digital out 21
#define VOLTAGE_ANALOG_INPUT_PIN A8         // Digital out 22
#define SPARE_1_INPUT_PIN A9                // Digital out 23

// Digital pins definitions
// If it's commentend out, it's in use above
#define UNUSED_PIN_0 0          // RX1
#define UNUSED_PIN_1 1          // TX1
//#define UNUSED_PIN_2 2
//#define UNUSED_PIN_3 3
//#define UNUSED_PIN_4 4
//#define UNUSED_PIN_5 5    
//#define UNUSED_PIN_6 6
//#define UNUSED_PIN_7 7      
//#define UNUSED_PIN_8 8   
#define UNUSED_PIN_9 9         
//#define UNUSED_PIN_10 10  
#define UNUSED_PIN_11 11        // MOSI
#define UNUSED_PIN_12 12        // MISO
//#define UNUSED_PIN_13 13      // LED
//#define UNUSED_PIN_14 14      // Analogue A0
//#define UNUSED_PIN_15 15      // Analogue A1
//#define UNUSED_PIN_16 16      // Analogue A2 / SCL1
//#define UNUSED_PIN_17 17      // Analogue A3 / SDA1
//#define UNUSED_PIN_18 18      // Analogue A4 / SDA0
//#define UNUSED_PIN_19 19      // Analogue A5 / SCL0
//#define UNUSED_PIN_20 20      // Analogue A6
//#define UNUSED_PIN_21 21      // Analogue A7
//#define UNUSED_PIN_22 22      // Analogue A8
//#define UNUSED_PIN_23 23      // Analogue A9

// We don't use pins 24-39 as they're not required and dificult to access.



/* Thermistor value and treshold
 * The Delphi 12160855 or AEM 30-2012 sensor, like all thermistors don't have a linear curve
 * So to have a good precision on the full temperature scale, we use two different resistor values
 * to calculate the temperature. One for the low end to mid, and one for the high end.
 * Since we mesure engine coolant temperature, the high end reading must be accurate.
 * The reference resistors and the threshold to switch between them are determined by the value below.
 * A hysteresis is used to avoid changing the reference too often.
 */
// Values for coolant thermistor's resistors (R11 - High, R10 - Low)
// For the best results, measure the actual value on your specific board and use high precision %1 resistor or better.
// Should be between 14800.0 - 15200.0
// Important: Enter the value as float
#define COOL_THERMISTOR_RESISTOR_REFERENCE_HIGH 14960.0
// This is the PARALLEL VALUE of both the above reference resistor and a second one
// !!IMPORTANT!! Measure the resistance of R11 and R10 and put the two values into this calulator:
// https://www.allaboutcircuits.com/tools/parallel-resistance-calculator/
// Then paste the equivalent resistance below.
// Should be between 890.0 - 990.0
// Important: Enter the value as float
#define COOL_THERMISTOR_RESISTOR_REFERENCE_LOW 935.59

// Values for oil thermistor's resistors (R9 - High, R8 - Low)
// For the best results, measure the actual value on your specific board and use high precision %1 resistor or better.
// Should be between 14800.0 - 15200.0
// Important: Enter the value as float
#define OIL_THERMISTOR_RESISTOR_REFERENCE_HIGH 14960.0 //15410.0
// This is the PARALLEL VALUE of both the above reference resistor and a second one
// !!IMPORTANT!! Measure the resistance of R9 and R8 and put the two values into this calulator:
// https://www.allaboutcircuits.com/tools/parallel-resistance-calculator/
// Then paste the equivalent resistance below.
// Should be between 890.0 - 990.0
// Important: Enter the value as float
#define OIL_THERMISTOR_RESISTOR_REFERENCE_LOW 935.59

// The threshold values to toggle between high resistor and low resistor
#define THERMISTOR_RESISTOR_REFERENCE_LOW_THRESHOLD 55
#define THERMISTOR_RESISTOR_REFERENCE_HIGH_THRESHOLD 50

// There is an onboard tension divider that allow the Teensy to read the supply voltage (~12V).
// The raw voltage is too high for the Teensy, so the voltage is divided with resistors.
// For the best results, measure the actual values on your specific board and use high precision %1 resistor or better.
// Important: Enter the value as float
// These values below allow a voltage range from 0 to 18V
#define VOLTAGE_DIVIDER_R1 6800.0 // R4
#define VOLTAGE_DIVIDER_R2 1500.0 // R3

// Adjust this in the range 0-255 to change screen brightness when car lights are turned on
// Should be greater than 0, otherwise displays are off
#define MINIMUM_BRIGHTNESS 2

// Buzzer Configuration
#define BUZZER_HZ 1500
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

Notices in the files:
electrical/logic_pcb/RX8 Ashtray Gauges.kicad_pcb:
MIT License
